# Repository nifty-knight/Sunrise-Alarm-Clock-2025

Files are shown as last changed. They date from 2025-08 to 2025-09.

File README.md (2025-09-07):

# Sunrise-Alarm-Clock-2025

Do you hate the sound of your alarm in the morning? Would you rather wake up peacefully, gently, and - most importantly - <i>quietly</i>?
If so, consider making a Sunrise Alarm Clock! This repo is part of an [instructable tutorial](https://www.instructables.com/DIY-Sunrise-Alarm-Clock-With-Arduino/) on how to do just that.

Note that Full_program_v3.5 is the most updated version; v4 is still in progress.

For those who don't want to click suspicious hyperlinked text: https://www.instructables.com/DIY-Sunrise-Alarm-Clock-With-Arduino/

For a condensed and more technical description of the project, read the Project Description pdf. Note that the corresponding code can be found in the oo-refactoring branch of this repository.

## Clock User Instructions

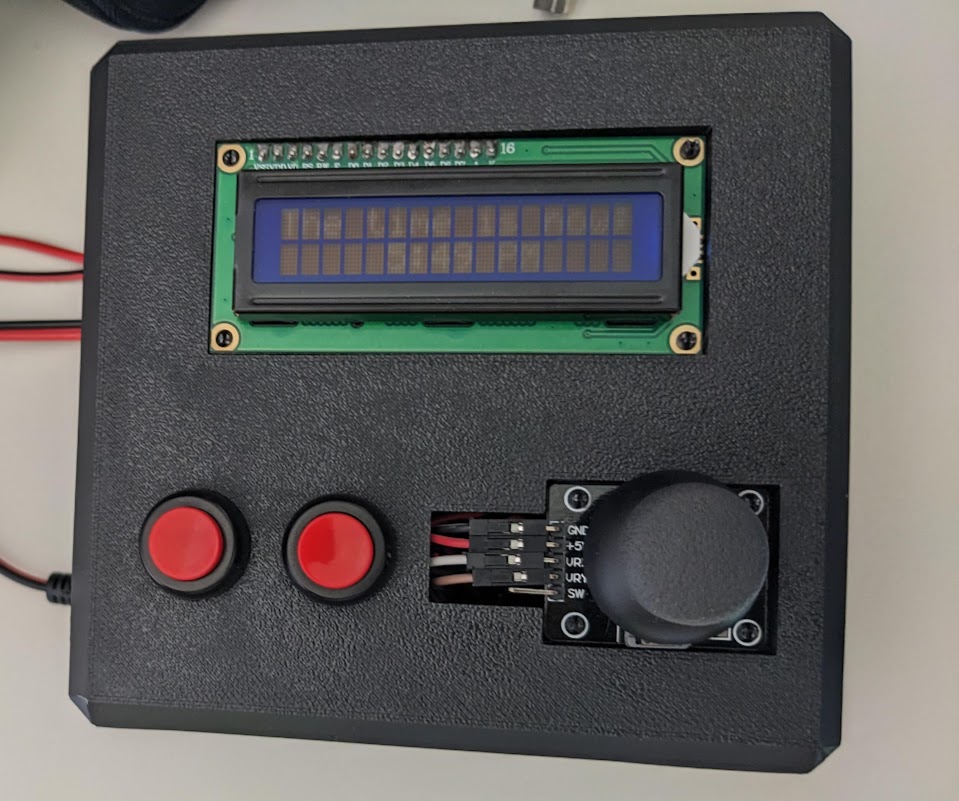
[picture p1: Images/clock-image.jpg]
Clock Image


### Display
Pressing the select button will turn the display on, which shows a user menu. From the menu, you can:

**Set Alarm Time** - 
This will lead to a series of menus where you can select AM/PM, hour, and minute (in 15-minute increments) for the desired
alarm time. Toggle the joystic up and down to change the values, and use the Select button to select desired values. Moving the
joystick to the right will also select the current value, while moving the joystick to the left will go back to the previous menu 
or cancel the set alarm process if there are no more previous menus. Currently, only one alarm can be set at a time.

**Set Current Time** - 
This works similarly to setting the alarm time, but it affects the current time stored by the clock module. Caution! Currently, it 
can only be set in 15-minute increments (0, 15, 30, 45).

**Move Time Forwards 1hr** -
This function is meant for daylight savings time; select this menu to move the current time forwards one hour.

**Move Time Backwards 1 hr** -
This function is meant for daylight savings time; select this menu to move the current time backwards one hour.

**Toggle Alarm** -
Selecting this menu option will not change the time set for the alarm, but will toggle its on/off state (ex. if the alarm was previously ON, 
it will be OFF after toggling, and vice versa). If the alarm is OFF, the light will not turn on even when the current time matches the set alarm time. 
This provides a quick and easy way to turn on/off the alarm for weekdays/weekends.

### Time Button
The leftmost button is the Time button, press it to display the current time. The display will turn off automatically after 5 seconds.

### Select Button
The rightmost button is the Select button, it is used for selecting menu options.

### Joystick
The joystick is used for switching between menus. It can also be used for selection and cancellation (the 'back' function) when setting times.

### Start/Reset
The current time must be set on program start, but afterwards it will retain the time even if the Arduino loses power, as long as there is a battery powering the RTC. 
However, currently any set alarm will have to be reset if the Arduino loses power or if the program is reset.

## Notes
- Note that v3.5 is the most updated version; v4 is still in progress.
- This code is still being updated and improved, check back for better and more robust versions of the program!

## Features to add
- Add unit testing framework
- Add interruptibility to all reads/displays, right now only some of them are interruptible
- Include a function to prevent the user from setting an alarm less than fadetime mins from now
- Edit program to use getFadeStartTime() instead of setFadeStartTime() - all tests for program first - this is refactoring
- Check that all functions to do with milliseconds and longs are subtraction - no addition to prevent rollover errors
- Add function so that looking at menus doesn't affect the light turning on or not
- Modify setHour() and setMin() functions to reduce coupling of cursor variable with magic number
- Add fun messages to print to lcd using displayTime
    - "The time is now..." 
    - LUNCHTIME
    - Why are you awake? You have 1 hrs, 39 mins, and 56 secs of sleep time left
    - 11AM!!! YOU'RE LATE FOR WORK/SCHOOL haha just kidding it's actually ___ (real time)
    - Do you really need to pee again? I need to sleep too...
    - ... it's the witching hour~~ ...
- Allow current time and/or alarm time to be set at any minute (not just 15-minute increments) - might use sliders for two unit places (eg. _ _ )
- Potentially add support for multiple alarms

## Changelog/Completed Features

v3.5 - Added functionality to prevent the time from resetting if the Arduino loses power (requires cell battery for the RTC module)

v3 - Added interruptibility for reading current time & displaying current alarm state - pressing the Select button returns to the mains menu

v3 - Added 'back' functions and cancellation for setting alarm/current time

v3 - Added menu options for daylight savings to move the current time ahead/behind 1 hr

v2 - More custom arrow icons, changed menu switch directions (up/down instead of left/right)

v1 - Added custom icons for arrows

v1 - Added a timer to automatically switch off the LCD after 25 secs of inactivity, which resets on button click/joystick movement

v1 - Created menus for setting alarm time & current time

v1 - Added LCD menu switching with the joystick

v1 - Added functionality to display the current time for 5 seconds on Time button press

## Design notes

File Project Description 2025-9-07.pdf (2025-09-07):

Breanne Chan

Project Description: Sunrise Alarm Clock

The Sunrise Alarm Clock was a personal project that I designed and built from scratch, involving designing and soldering an electronic circuit and components, developing C++ code for an Arduino Uno, and designing a 3D-printed case using a CAD program.

Electronics
Circuit Diagram

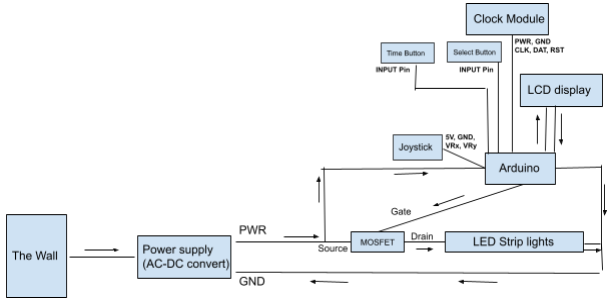
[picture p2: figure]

There were several technical challenges involved in the design of this circuit. First, I had to create a system where a light source would gradually increase in brightness. Although I initially tried to use an array of small LED lights, lighting up one row at a time, I found that they were not bright enough to serve as a wakeup system. Ultimately, I realized that I needed brighter lights, which required more power than the Arduino could output. Changing the light source meant I needed to carefully consider the appropriate power source for my project, and also find a separate device to modulate the brightness of the light source. Eventually, I settled on using 12V LED strip lights, since the Arduino Uno could also be powered with 12 volts, wired the Uno’s lower-voltage digital PWM pins to an external MOSFET module serving as the brightness controller, and used a wall outlet for consistent, reliable power.

In the final circuit, an Arduino Uno serves as the “brain” for the project, controlling the light and user input/output system. The circuit makes use of a DS1302 Real-Time Clock module to keep accurate track of time, and an N-channel MOSFET to control the brightness of the LED strip light. Two momentary push buttons and a joystick are used to set or modify the alarm or current time, while a 16x2 liquid crystal display shows information to the user. A 12V DC power supply converts the power provided from a wall outlet into the appropriate voltage and current levels for the Arduino and LED strip lights.

Code

In my first iteration of the code, my primary aim was simply to build a full, working system. To do so, I broke down the large goal - creating a sunrise alarm clock - into several smaller chunks, such as getting the light system working, creating a user input/output system, implementing functionality to modify and track time accurately, etc. and wrote programs to solve each of those smaller problems independently. While making these programs, I was constantly researching and reading documentation to understand the capabilities of external software libraries that I used as well as the inputs/outputs of my hardware. Finally, I used what I’d learnt in the process of creating each small program to recombine them and create the complete system.

However, the original program I created was not without flaws. For instance, it was written in a messy procedural pattern and was neither easy to read nor simple to extend. Furthermore, the logic I used sometimes induced unwanted blocking, where the microprocessor was waiting for user input and could not check whether it was time for the light system to start. Currently, I am developing a refactored version of my original code to address all these problems, where I am applying object-oriented design concepts to create a class hierarchy which increases cohesiveness, creates modularity, and decouples separate functionality from each other. Additionally, I plan to use finite-state machine models with a set number of states to represent a tick-based update loop, preventing unwanted blocking.

UML Class Diagram V1

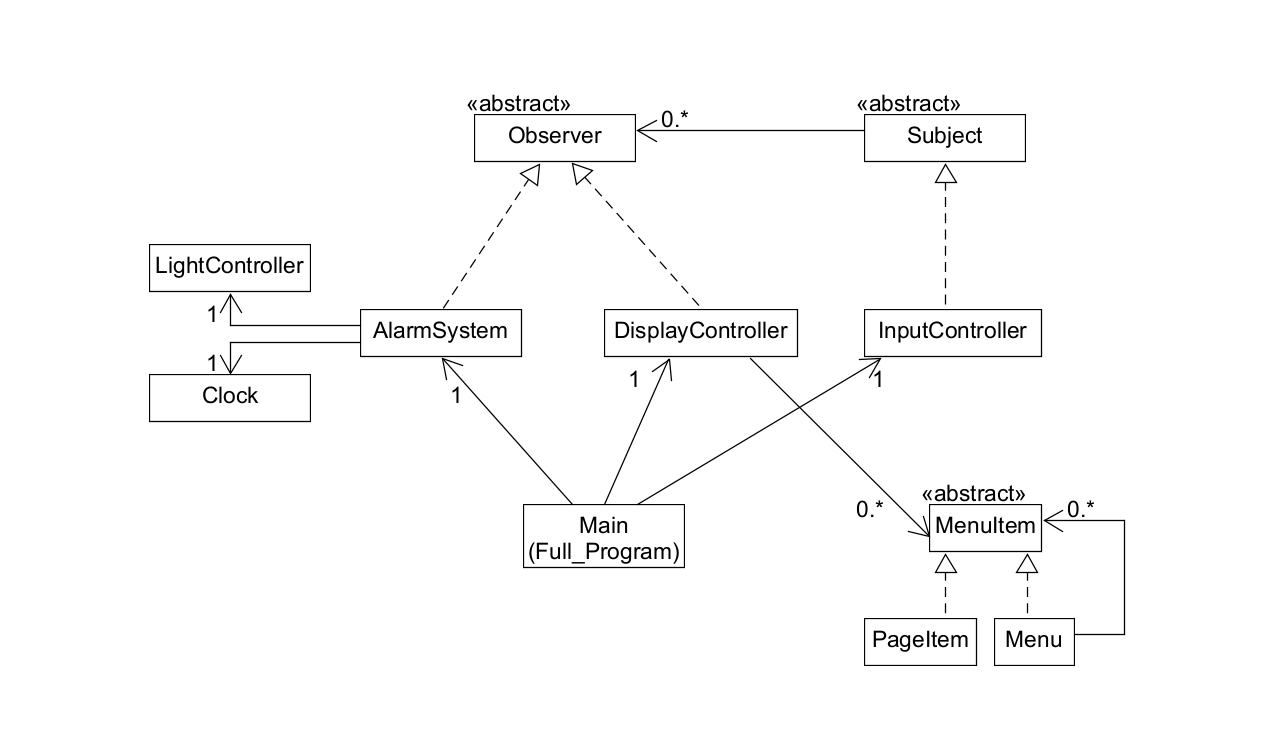
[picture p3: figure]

- Initial ideas for class hierarchy
- Main is the .ino file from which the program starts
- InputController listens for input from the user, notifies AlarmSystem and DisplayController to act
- Pages/Menus in the user display are represented by the composite MenuItem pattern

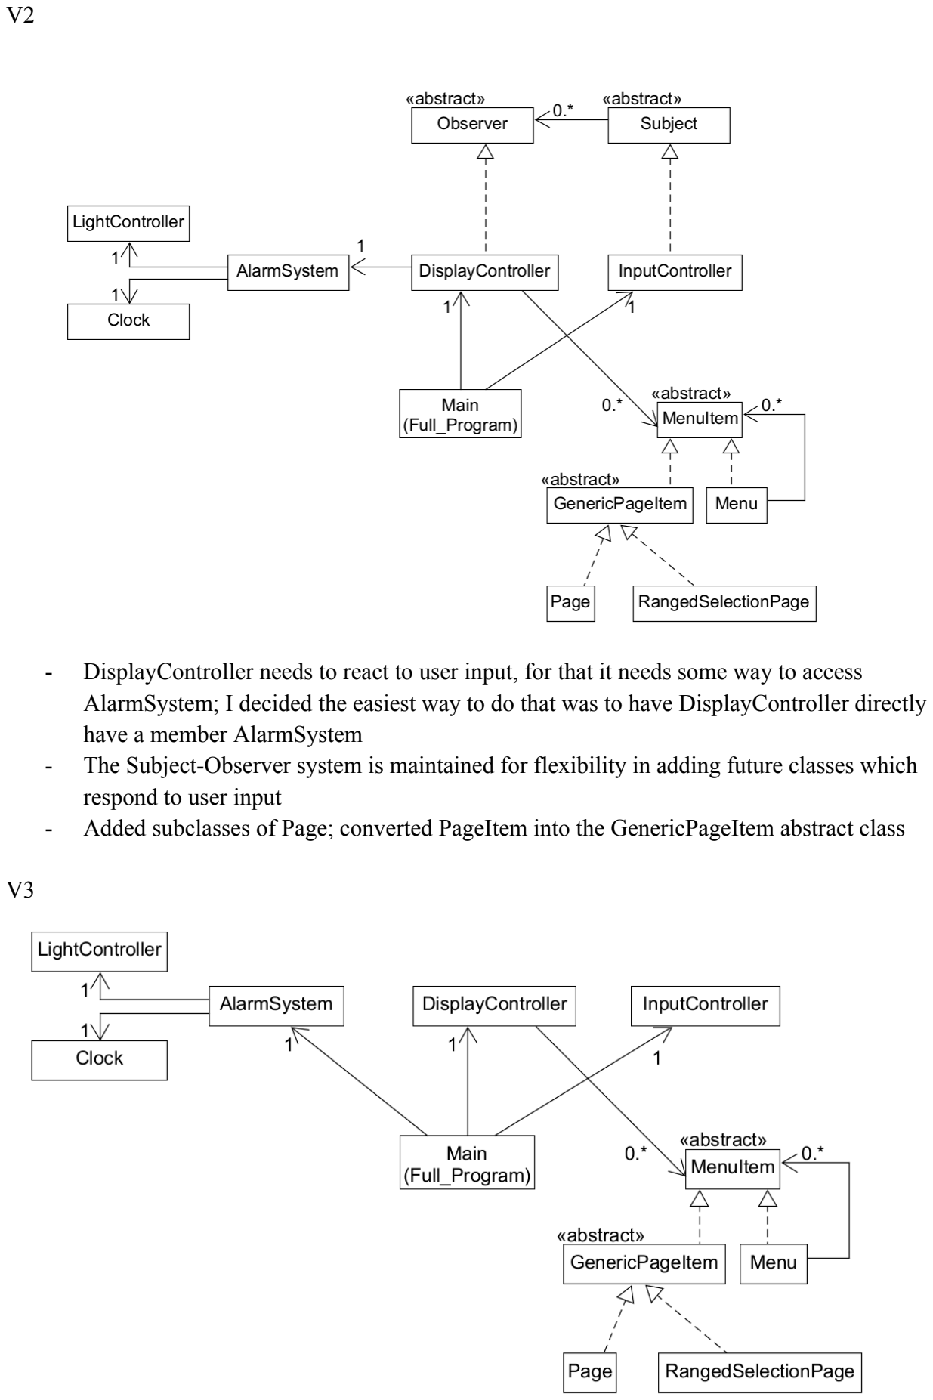
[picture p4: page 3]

V2

- DisplayController needs to react to user input, for that it needs some way to access AlarmSystem; I decided the easiest way to do that was to have DisplayController directly have a member AlarmSystem
- The Subject-Observer system is maintained for flexibility in adding future classes which respond to user input
- Added subclasses of Page; converted PageItem into the GenericPageItem abstract class

V3

- Realized that since Main instantiates and can access a member DisplayController and InputController, the Subject-Observer pattern only increases coupling of the program
- Removed the Subject-Observer system entirely, DisplayController will be the class whose responsibility is to process all user input

V4

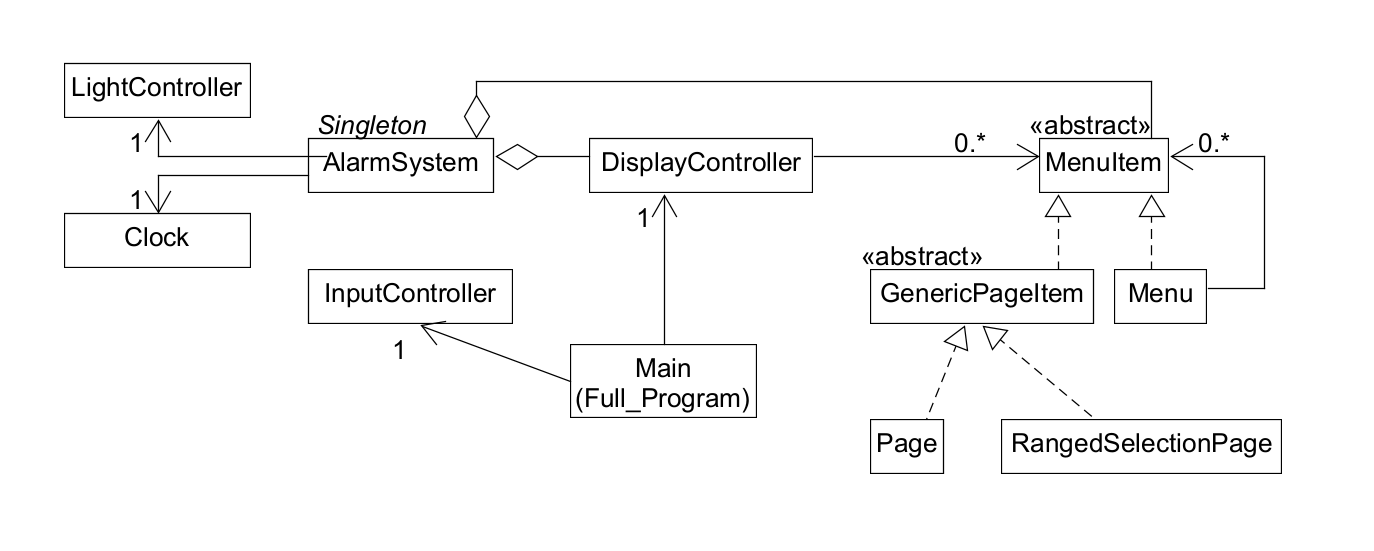
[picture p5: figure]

- Refactored AlarmSystem into a singleton class - since there really only should be one AlarmSystem
- Note that the notation for singleton is not typical; I just wanted to explicitly write it since I have not included fields and methods in the diagrams
- Note that I also have not included the association for AlarmSystem to itself (where it contains a field for an instance of itself)

Potential Future Improvements
- Refactor DisplayController, InputController, potentially also LightController and Clock to be singleton classes
- They each correspond to particular hardware modules
- However, doing this may increase complexity of code without much benefit
- May add a RangedSelectionMenu as a child of Menu
- Alternatively, may add RangedSelectionBehaviour class and implement a composition structure with both Page and Menu
- Both DisplayController and MenuItem contain associations with AlarmSystem; however, DisplayController also contains a collection of MenuItem. Can I remove the extra reference from DisplayController to reduce coupling?

Computer-Aided Design

The CAD design for this project included a base with snap-fit plug mounts to hold the PCB modules and a lid with similar mounts for a 16x2 LCD, joystick, and two panel mount buttons.

I started the design by creating mounts for each of the PCB modules (Arduino, RTC, MOSFET, etc). I initially started with a design that partially covered each side of the module. However, while researching alternative solutions, I came across a Medium article (https://medium.com/@williamtech/3d-printing-snap-fit-mounting-plugs-for-pcbs-a2668a159a8c) experimenting with snap-fit plugs, and consequently decided to try and create my own in Onshape, based off of William Andrews' design. I tested several different sizes and tolerances before settling on a final size and creating prototype mounts for each module.

After that, I started experimenting with lid design. I tried a few versions of a spring-loaded lid, but ultimately pivoted to a much simpler brim design which was simple and clean-looking. However, the new lid design was causing a problem; because the lid was hollow on the inside, but the snap-fit plugs stuck out of the top, each print required a lot of support, no matter how I oriented the design. I wasn't sure how to resolve this problem until a family member suggested that I recess the plugs into the lid, so that the top of each sat flush with the surface of the lid. After some trial and error, I was able to create a final lid design that reduced my material use by 15% and decreased print time by 40 minutes!

Note: I also wrote an in-depth Instructables tutorial (https://www.instructables.com/DIY-Sunrise-Alarm-Clock-With-Arduino/) for this project, which was featured by the editors of the site and garnered over 100 views in its first two weeks after publishing.

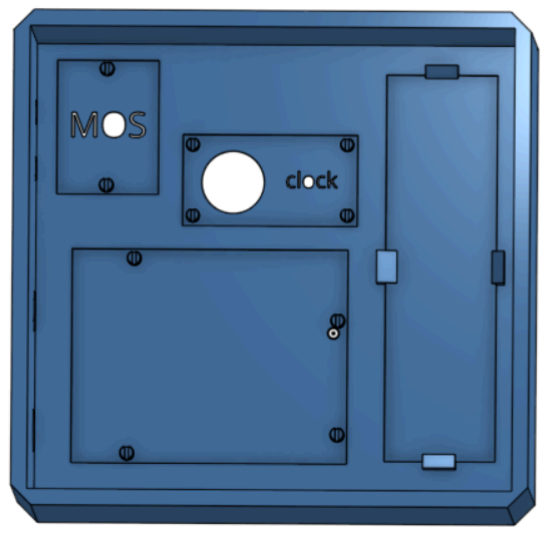
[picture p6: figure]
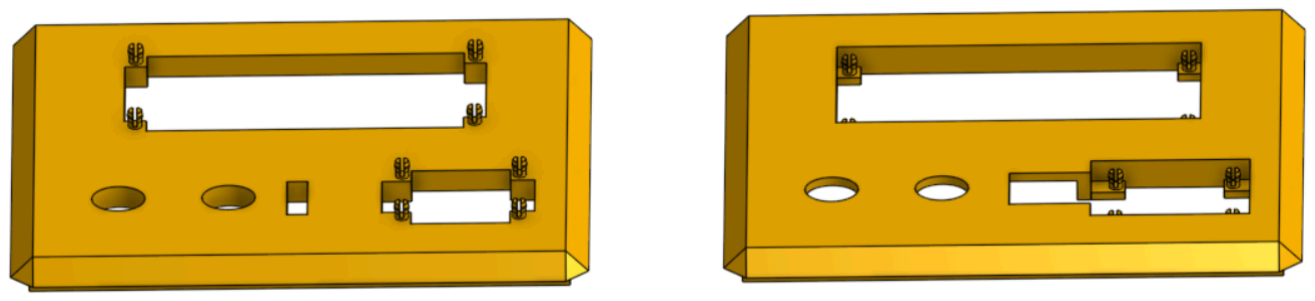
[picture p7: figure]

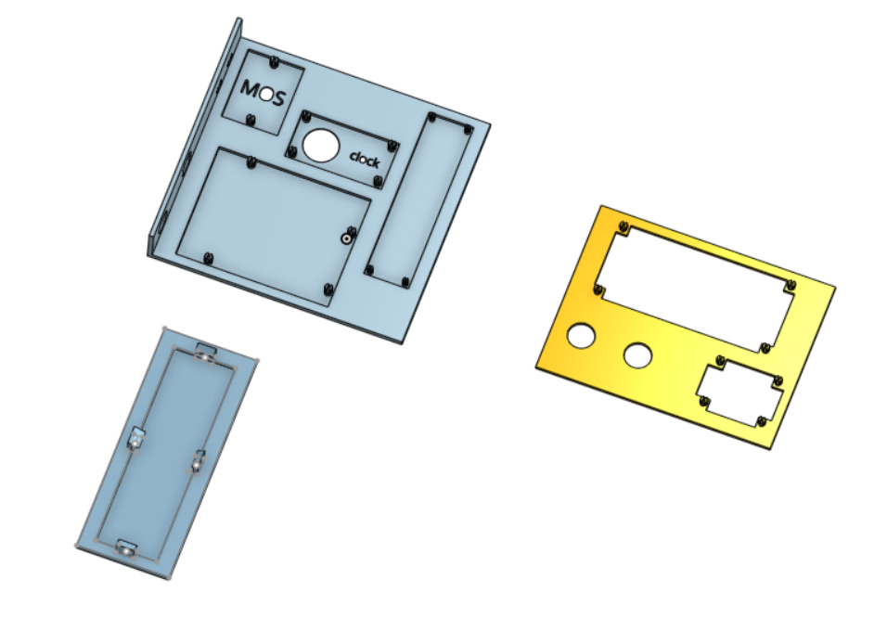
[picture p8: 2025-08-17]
Images/Onshape Pictures/Screenshot 2025-08-16 085841.png

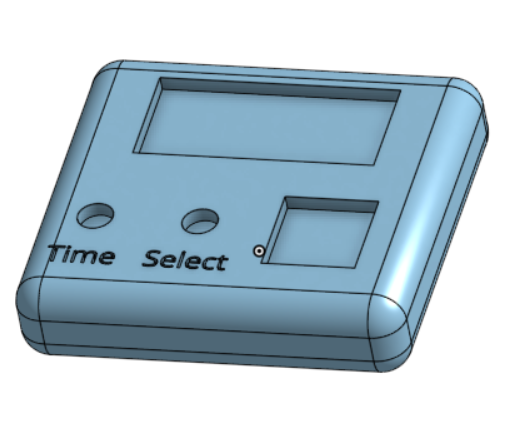
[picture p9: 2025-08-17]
Images/Onshape Pictures/Screenshot 2025-08-16 090458.png

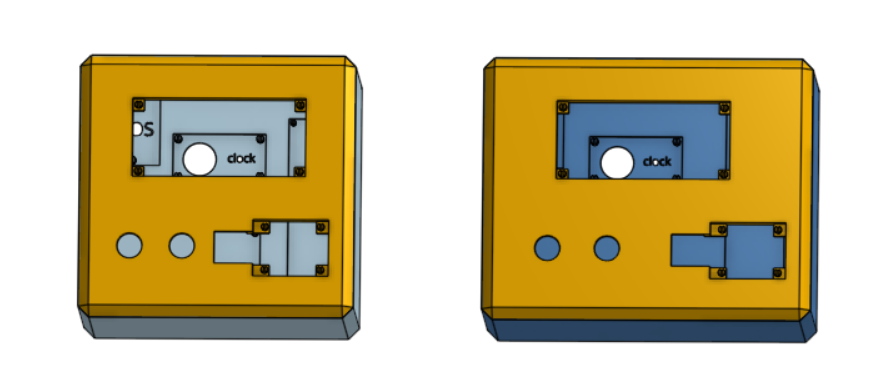
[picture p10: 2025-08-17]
Images/Onshape Pictures/Screenshot 2025-08-16 092152.png

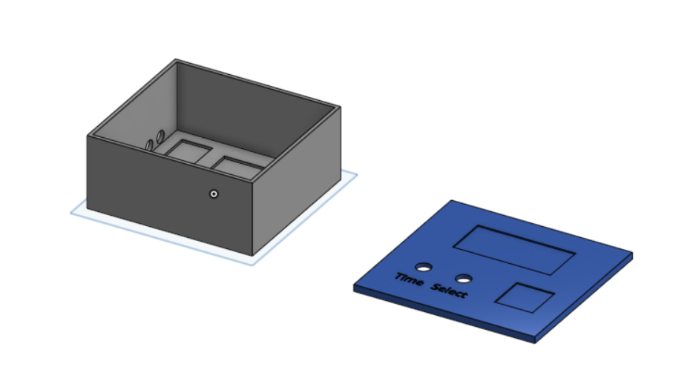
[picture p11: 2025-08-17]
Images/Onshape Pictures/Screenshot 2025-08-16 090216.png

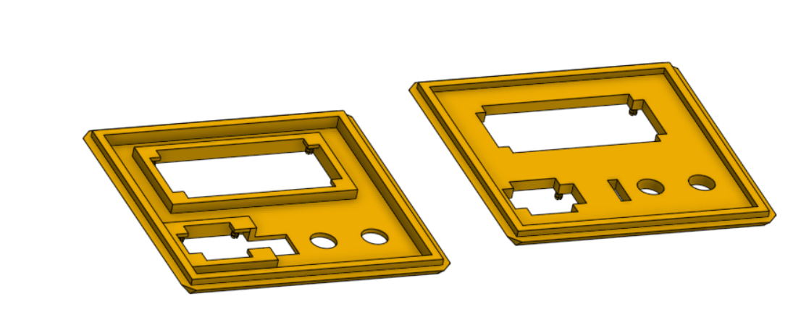
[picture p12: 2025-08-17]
Images/Onshape Pictures/Screenshot 2025-08-16 090546.png

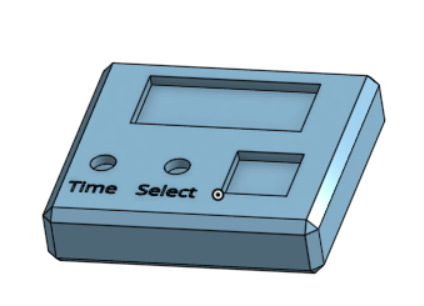
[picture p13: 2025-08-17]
Images/Onshape Pictures/Screenshot 2025-08-16 090327.png

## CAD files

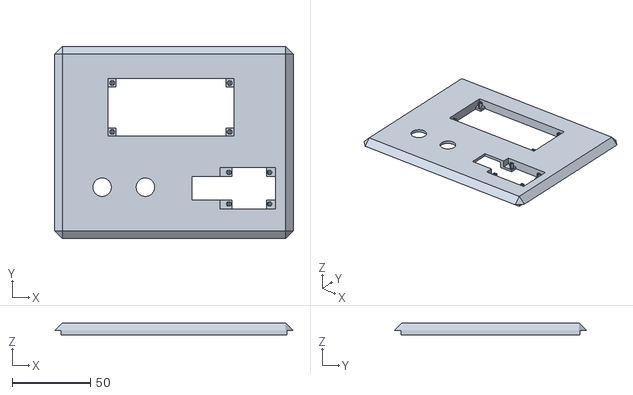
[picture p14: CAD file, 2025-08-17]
STL Files/Lid - Large.stl
153.0 x 123.0 x 8.00

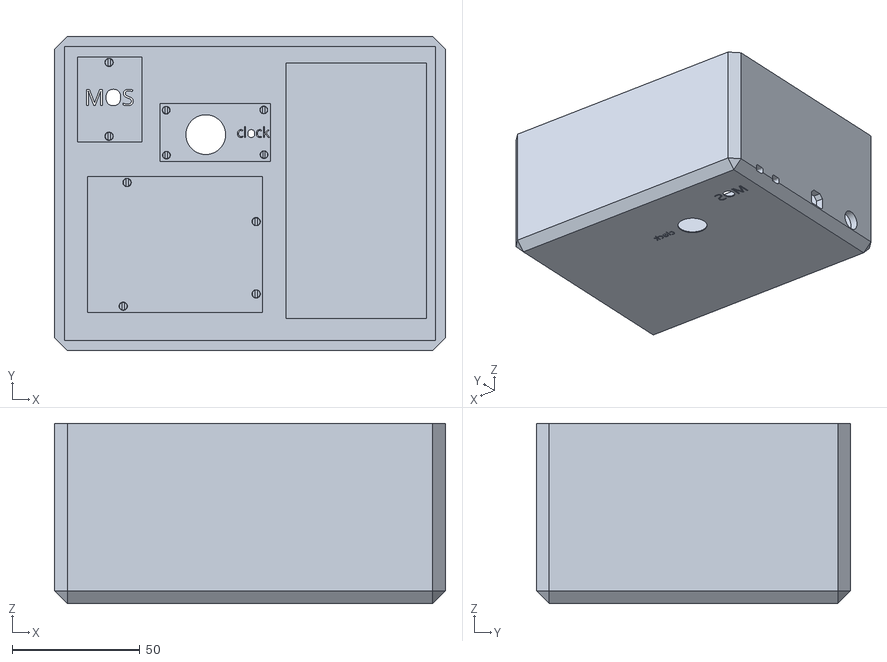
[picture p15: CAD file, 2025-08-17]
STL Files/Box - Large.stl
153.0 x 123.0 x 70.5

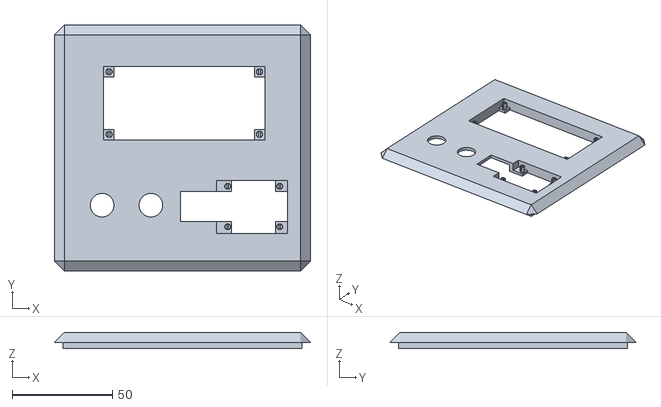
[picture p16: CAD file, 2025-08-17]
STL Files/Lid - Original.stl
128.0 x 123.0 x 8.00

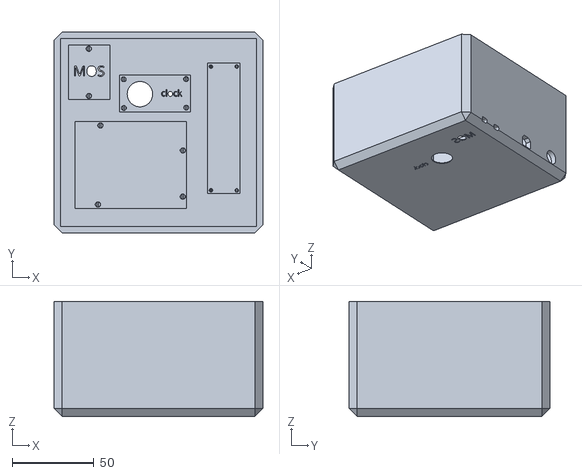
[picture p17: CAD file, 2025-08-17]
STL Files/Box - Original.stl
128.0 x 123.0 x 70.5

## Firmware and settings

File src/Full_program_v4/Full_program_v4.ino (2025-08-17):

#include <LiquidCrystal.h>
#include <Arduino.h>
#include <Ds1302.h>

void on();
void off();
void displayMainMenu();
void selectPage(int index);
bool joystickUp();
bool joystickDown();
bool joystickLeft();
bool joystickRight();
void switchPage(int index);
String setPeriod();
int setHour();
int setMin();
int convertTo24HrTime(int hr, String s);
void daylightSavingChange(int change);
bool pastFadeStartTime(Ds1302::DateTime alarm);
void printUpArrow();
void printDownArrow();
// void printLeftArrow();
// void printRightArrow();
void turnLightOff();
void printCurrentTime();
void printAlarmState();
void resetActivityTimer();

byte UpArrow[8] = {
  0b00000,
  0b00000,
  0b00000,
  0b00100,
  0b01110,
  0b11111,
  0b00000,
  0b00000
};

byte DownArrow[8] = {
  0b00000,
  0b00000,
  0b11111,
  0b01110,
  0b00100,
  0b00000,
  0b00000,
  0b00000
};

byte RightArrow[8] = {
  0b00000,
  0b01000,
  0b01100,
  0b01110,
  0b01110,
  0b01100,
  0b01000,
  0b00000
};

byte LeftArrow[8] = {
  0b00000,
  0b00010,
  0b00110,
  0b01110,
  0b01110,
  0b00110,
  0b00010,
  0b00000
};

const int delayTime = 525;
const int readTime = 3500;
const int noActivityTime = 20000; // 25 secs

const int PIN_CLK = 7;
const int PIN_DAT = 6;
const int PIN_ENA = 5;  // RST on the module

const String PERIOD_ERROR = "ERROR";
const int HOUR_ERROR = -1;
const int MIN_ERROR = -1;
const int YEAR_ERROR = 0;

// DS1302 RTC instance
Ds1302 rtc(PIN_ENA, PIN_CLK, PIN_DAT);
Ds1302::DateTime alarmTime;
Ds1302::DateTime fadeStartTime;
bool alarmIsOn = false;        // initialized as off originally

// Creates an LCD object. Parameters: (rs, enable, d4, d5, d6, d7)
LiquidCrystal lcd(13, 11, 10, 8, 3, 2);
const uint8_t backlightPin = A5; // A on LCD
bool displayOn = true;

const uint8_t displayButtonPin = A3; // displays current time when pressed - previously A0
const uint8_t selectButtonPin = A4; // used to select options for menu and turn the light off
int index;                     // menu index (aka menu "page/tab")
const int MAX_MENU_INDEX = 4;  // represents 5 allowed pages for main menu - set alarm, set current time, current time +1hr, current time -1hr, toggle alarm

const uint8_t X_pin = A1;  // analog pin connected to X output of joystick
const uint8_t Y_pin = A0; // analog pin connected to Y output of joystick
int X_pos;
int Y_pos;

unsigned long startTime; // starting time for activity timer

const int ledPin = 9; // MOSFET control pin (SIG)
bool lightIsOn = false; // keeps track of the state of the LED light; off initially
float fadeLength = 20; // time in minutes for the light to go from 0 to full brightness
int brightness = 0; // 0-255
int brightnessMultiplier = 1; // Range from 1..*, the smaller the number the brighter it gets
unsigned long long ledStartTime; // used for controlling light brightness
unsigned long long waitTime; // the amount of delay before increasing the brightness of the light

void setup() {
  pinMode(X_pin, INPUT);
  pinMode(Y_pin, INPUT);
  pinMode(selectButtonPin, INPUT);
  pinMode(displayButtonPin, INPUT);
  pinMode(ledPin, OUTPUT);
  turnLightOff();
  startTime = millis();
  ledStartTime = millis();

  if (rtc.isHalted()) {
    rtc.init();

    Ds1302::DateTime currentTime = {
      .year = 2025,
      .month = Ds1302::MONTH_AUG,
      .day = 9,
      .hour = 16,
      .minute = 48,
      .second = 0,
      .dow = Ds1302::DOW_SAT
    };

    rtc.setDateTime(&currentTime);
  }

  pinMode(backlightPin, OUTPUT);

  // set up the LCD's number of columns and rows:
  lcd.begin(16, 2);
  // Clears the LCD screen
  lcd.clear();
  lcd.createChar(2, UpArrow);
  lcd.createChar(3, DownArrow);
  off();
}

void loop() {

  if (pressed(displayButtonPin)) {
    on();
    printCurrentTime();
  }

  if (pressed(selectButtonPin)) {

    if (lightIsOn) {
      turnLightOff();
      delay(delayTime);
    } else if (displayOn) {
      resetActivityTimer();
      selectPage(index);
    } else {
      resetActivityTimer();
      displayMainMenu();
    }
  }

  if (displayOn) {
    if (joystickUp()) switchPage(-1);
    else if (joystickDown()) switchPage(1);
  }

  if (displayOn && ((millis() - startTime) > noActivityTime)) {
    off();
  }

  if (alarmIsOn && !lightIsOn && nowIsTime(fadeStartTime)) {
    setupFade();
  } else if (alarmIsOn && lightIsOn && (brightness < 255)) { // light is on, not at full brightness
    if ((millis() - ledStartTime) >= waitTime) {
      brightness++;
      analogWrite(ledPin, brightness);
      ledStartTime = millis();
    }

  }
}

// EFFECTS: Sets up the variable needed to start fading in the light in the while loop
void setupFade() {
  lightIsOn = true;
  waitTime = abs(round(fadeLength * (60L * 1000L) / 255.0)) * brightnessMultiplier; // * multiplier because I find full brightness too much
  brightness = 1;
  analogWrite(ledPin, brightness);
  ledStartTime = millis();
}

// REQUIRES: time is not null
// EFFECTS: Returns true if the current time matches the given time (up to the second)
//          note: returns true if the hour and minute and second all match (when setting alarm time, give user option only for hour and minute, set time to zero)
//               - matches second +- 8 secs
bool nowIsTime(Ds1302::DateTime time) {
  Ds1302::DateTime now;
  rtc.getDateTime(&now);

  if ((now.hour == time.hour) && (now.minute == time.minute) 
      && ((now.second <= time.second + 8) || (now.second >= time.second - 8))) return true;
  else {
    return false;
  }
}

// EFFECTS: Returns true if the button connected to the given pin is being pressed
//          - note that the buttons I am using are backwards - let current flow when not pressed, block current when they are pressed - eg. 0 = pressed, 1 = not pressed
// FOR INVERTED BUTTONS
bool pressed(int pin) {
  if (digitalRead(pin)) {
    return false;
  } else {
    return true;
  }
}

// EFFECTS: Returns true if the button connected to the given pin is being pressed
//          - note that the buttons I am using are backwards - let current flow when not pressed, block current when they are pressed - eg. 0 = pressed, 1 = not pressed
// FOR NON-INVERTED BUTTONS - uncomment the below pressed() function and comment out the above pressed() function
// bool pressed(int pin) {
//   if (digitalRead(pin)) {
//     return true;
//   } else {
//     return false;
//   }
// }

// EFFECTS: Guides user through setting a new time and returns the time
Ds1302::DateTime userSetTime() {

  Ds1302::DateTime currentTime;
  rtc.getDateTime(&currentTime); 

  int hr = 1;
  int min = 0;
  int year = currentTime.year;

  String period = setPeriod();
  if (period.equals(PERIOD_ERROR)) {
    year = YEAR_ERROR;
  } else {
    while (true) {
      hr = setHour();
      if (hr == HOUR_ERROR) {
        period = setPeriod();
        if (period.equals(PERIOD_ERROR)) {
          year = YEAR_ERROR;
          break;
        }
      } else {
        min = setMin();
        if (min == MIN_ERROR) {
          continue;
        } else {
          hr = convertTo24HrTime(hr, period);
          break;
        }
      }
    }
  }

  Ds1302::DateTime time = { // note that day, month, dow are fairly random; only time (and year for the error) matters here
    .year = year,
    .month = currentTime.month,
    .day = currentTime.day,
    // .day = day,--> this should be the final version
    .hour = hr,
    .minute = min,
    .second = 0,
    .dow = currentTime.dow
  };

  return time;
}

// REQUIRES: LCD display is on
// EFFECTS: does the period selection menu, allows user to select AM or PM, returns user selection
//          note: 0 = AM, 1 = PM
String setPeriod() {
int cursor = 0;
  lcd.clear();
  lcd.setCursor(3, 0);
  lcd.print("Select: AM");
  lcd.setCursor(14, 0);
  printUpArrow();
  lcd.setCursor(14, 1);
  printDownArrow();
  delay(delayTime);

  while (true) {
    if (pressed(selectButtonPin) || joystickRight()) {
      delay(delayTime);
      if (cursor == 0) return "AM";
      else return "PM";
    } else if (joystickUp()) {
      cursor = 0;
      lcd.setCursor(11, 0);
      lcd.print("A");
    } else if (joystickDown()) {
      cursor = 1;
      lcd.setCursor(11, 0);
      lcd.print("P");
    } else if (joystickLeft()) {
      delay(delayTime);
      // Serial.print("To the left\n");
      return PERIOD_ERROR;
    }
  }
}

// EFFECTS: does the minute selection menu, allows user to select an hour between 1-12 inclusive, returns user selection
int setHour() {
  int cursor = 7;
  lcd.clear();
  lcd.setCursor(1, 0);
  lcd.print("Set Hour: 07 "); // NOTE: this has to change along w/ initial cursor number if changed
  printUpArrow();
  lcd.setCursor(14, 1);
  printDownArrow();
  delay(delayTime);

  while (true) {
    if (pressed(selectButtonPin) || joystickRight()) {
      delay(delayTime);
      return cursor;
    } else if (joystickUp()) {
      if (cursor <= 1) cursor = 12;
      else cursor--;
      lcd.setCursor(11, 0);
      if (cursor < 10) lcd.print("0");
      lcd.print(cursor);
      delay(delayTime);
    } else if (joystickDown()) {
      if (cursor >= 12) cursor = 1;
      else cursor++;
      lcd.setCursor(11, 0);
      if (cursor < 10) lcd.print("0");
      lcd.print(cursor);
      delay(delayTime);
    } else if (joystickLeft()) {
      delay(delayTime);
      return HOUR_ERROR;
    }
  }
}

// EFFECTS: does the minute selection menu, allows user to select a minute between 0-59, returns user selection
// for now only supports 15-min increments -> in the future may support 5-min increments
int setMin() {
  int range[] = {0,15,30,45};
  int size = 4; // size of the range[] array

  int cursor = 0;
  lcd.clear();
  lcd.setCursor(2, 0);
  lcd.print("Set Min: 00 "); // NOTE: this has to change along w/ initial cursor number if changed
  lcd.setCursor(14, 0);
  printUpArrow();
  lcd.setCursor(14, 1);
  printDownArrow();
  delay(delayTime);

  while (true) {
    if (pressed(selectButtonPin) || joystickRight()) {
      delay(delayTime);
      return range[cursor];
    } else if (joystickUp()) {
      if (cursor <= 0) cursor = (size - 1);
      else cursor--;
      lcd.setCursor(11, 0);
      if (range[cursor] < 10) lcd.print("0");
      lcd.print(range[cursor]);
      delay(delayTime);
    } else if (joystickDown()) {
      if (cursor >= (size - 1)) cursor = 0;
      else cursor++;
      lcd.setCursor(11, 0);
      if (range[cursor] < 10) lcd.print("0");
      lcd.print(range[cursor]);
      delay(delayTime);
    } else if (joystickLeft()) {
      return MIN_ERROR;
    }
  }
}

// EFFECTS: Takes an hour in 12-hr time and AM or PM, and determines the time in 24-hr time
int convertTo24HrTime(int hour, String period) {
  if (period == "PM") {
    return hour += 11;
  } else return hour - 1;
}

// EFFECTS: calls new routine depending on the current menu and page
void selectPage(int index) {
  delay(delayTime);
  switch (index) {
    case 0: {
      alarmIsOn = true;
      displayMainMenu();
      Ds1302::DateTime temp = userSetTime();
      if (pastFadeStartTime(temp)) { // If it is past the start time, don't let the user set the alarm
        lcd.clear();
        lcd.setCursor(1, 0);
        lcd.print("Alarm not set");
        lcd.setCursor(0, 1);
        lcd.print("Too close to now");
        delay(readTime);
        displayMainMenu();
      } else if (temp.year != YEAR_ERROR) { // If year==YEAR_ERROR, that means user cancelled
        alarmTime = temp;
        setFadeStartTime();
        printAlarmState(); 
      } else {
        lcd.clear();
        lcd.setCursor(3, 0);
        lcd.print("Set alarm");
        lcd.setCursor(3, 1);
        lcd.print("cancelled");
        delay(readTime);
        displayMainMenu();
      }
      break;
    }
    case 1: {
      Ds1302::DateTime temp = userSetTime();
      if (temp.year != YEAR_ERROR) { // If year==YEAR_ERROR, that means user cancelled
        rtc.setDateTime(&temp);
        printCurrentTime();
      } else {
        lcd.clear();
        lcd.setCursor(3, 0);
        lcd.print("Set time");
        lcd.setCursor(3, 1);
        lcd.print("cancelled");
        delay(readTime);
        displayMainMenu();
      }
      break;
    }
    case 2: { // Change time for daylight savings forward 1hr
      daylightSavingChange(1);
      printCurrentTime();
      break;
    }
    case 3: {
      daylightSavingChange(-1);
      printCurrentTime();
      break;
    }
    case 4: {
      alarmIsOn = !alarmIsOn;
      printAlarmState();
      break;
    }
  }
}

// EFFECTS: switch the index and display the next page; 1 = to the right, -1 = to the left, other displays error on LCD
void switchPage(int next) {
  resetActivityTimer();
  if (next == 1) {
    if (index >= MAX_MENU_INDEX) {
      index = 0;
    } else index++;

  } else if (next == -1) {
    if (index <= 0) {
      index = MAX_MENU_INDEX;
    } else index--;

  } else {
    lcd.clear();
    lcd.print("ERROR next,switchPage");
  }

  setPage(index);

  delay(delayTime);
}

// EFFECTS: Turns on the lcd display and backlight and shows the main menu
void displayMainMenu() {
  index = 0;
  on();
  setPage(index);
  delay(delayTime);
}

// EFFECTS: Writes into the LCD display depending on the current menu and the given index
void setPage(int index) {
  lcd.clear();
  lcd.setCursor(0, 0);
  if (index == 0) {
    lcd.print("   Set alarm");
    lcd.setCursor(14, 0);
    printUpArrow();
    lcd.setCursor(14, 1);
    printDownArrow();
    //
  } else if (index == 1) {
    lcd.print("    Set time");  // Set time
    lcd.setCursor(14, 0);
    printUpArrow();
    lcd.setCursor(14, 1);
    printDownArrow();
  } else if (index == 2) {
    lcd.print("   Move time");
    lcd.setCursor(14, 0);
    printUpArrow();
    lcd.setCursor(0, 1);
    lcd.print(" forward 1hr");
    lcd.setCursor(14, 1);
    printDownArrow();
  } else if (index == 3) {
    lcd.print("   Move time");
    lcd.setCursor(14, 0);
    printUpArrow();
    lcd.setCursor(0, 1);
    lcd.print(" backward 1hr");
    lcd.setCursor(14, 1);
    printDownArrow();
  } else if (index == 4) {
    lcd.print(" Toggle alarm ");  // Alarm toggle
    printUpArrow();
    lcd.setCursor(14, 1);
    printDownArrow();
  } else {
    lcd.print("ERROR index out of bounds");
  }
}

// EFFECTS: Prints current time to the LCD, then turns off the display after readDelay sec
void printCurrentTime() {
  lcd.clear();
  lcd.setCursor(0, 0);
  lcd.print("The time is now:");
  lcd.setCursor(5, 1);
  Ds1302::DateTime currentTime;
  rtc.getDateTime(&currentTime);
  lcd.print(getTime(currentTime));

  long now = millis();
  long end = millis() + long(readTime);

  while (now < end) {
    if (pressed(selectButtonPin)) {
      displayMainMenu();
      return;
    }

    now = millis();
  }

  off();
}

// EFFECTS: Prints alarm state (on/off) and time to the LCD, then turns off the display after readDelay sec
// TODO: printCurrentTime & printAlarmState are very similar - combine into one function?
void printAlarmState() {
  lcd.clear();
  lcd.setCursor(0, 0);
  lcd.print(" Alarm is: ");
  if (alarmIsOn) {
    lcd.print("ON");
  } else lcd.print("OFF");
  lcd.setCursor(0, 1);
  lcd.print("Set to: ");
  lcd.print(getTime(alarmTime));
  
  long now = millis();
  long end = millis() + long(readTime);

  while (now < end) {
    if (pressed(selectButtonPin)) {
      displayMainMenu();
      return;
    }

    now = millis();
  }

  off();
}

// EFFECTS: Turns on the lcd display and backlight and shows the current time
void displayTime() {
  on();
  lcd.clear();
  lcd.setCursor(0, 0);
  lcd.print(F("The time is now: "));  // note: could do some funny things depending on the time
  lcd.setCursor(0, 1);
  Ds1302::DateTime now;
  rtc.getDateTime(&now);
  lcd.print(getTime(now));
  delay(4000);
  off();
}

// EFFECTS: Returns true if joystick has been moved upwards
bool joystickUp() {
  if (analogRead(Y_pin) <= 25) {
    return true;
  }
  return false;
}

// EFFECTS: Returns true if joystick has been moved downwards
bool joystickDown() {
  if (analogRead(Y_pin) >= 1000) {
      return true;
    }
    return false;
}

// EFFECTS: Returns true if joystick has been moved to the left
bool joystickLeft() {
  if (analogRead(X_pin) <= 15) {
    return true;
  }
  return false;
}

// EFFECTS: Returns true if joystick has been moved to the right
bool joystickRight() {
  if (analogRead(X_pin) >= 1000) {
    return true;
  }
  return false;
}

// MODIFIES: this - fadeStartTime
// EFFECTS: sets fadeStartTime to be 20 minutes before the given alarmTime - depends on how long I want the fade in to be
void setFadeStartTime() {

  fadeStartTime = alarmTime;

  if (alarmTime.minute >= fadeLength) {
    fadeStartTime.minute = alarmTime.minute - fadeLength;
  } else {
    int minLeft = fadeLength - alarmTime.minute;
    fadeStartTime.minute = 60 - minLeft;
    if (alarmTime.hour > 0) fadeStartTime.hour = alarmTime.hour - 1; 
    else fadeStartTime.hour = 23;
  }
}

// EFFECTS: Returns the time fadeLength minutes before the given alarmTime
Ds1302::DateTime getFadeStartTime(Ds1302::DateTime alarm) {

  int fadeLength = 20; // mins

  Ds1302::DateTime fadeStart = alarm;

  if (alarm.minute >= fadeLength) {
    fadeStart.minute = alarm.minute - fadeLength;
  } else {
    int minLeft = fadeLength - alarm.minute;
    fadeStart.minute = 60 - minLeft;
    if (alarm.hour > 0) fadeStart.hour = alarm.hour - 1; 
    else fadeStart.hour = 23;
  }

  return fadeStart;
}

void daylightSavingChange(int change) {
  Ds1302::DateTime old;
  rtc.getDateTime(&old);
  int newHour = old.hour + change;

  if (newHour < 0) newHour = 23;
  else if (newHour > 23) newHour = 0;

  Ds1302::DateTime newTime = { // note that day, month, year, dow are fairly random; only time matters here
    .year = old.year,
    .month = old.month,
    .day = old.day,
    .hour = newHour,
    .minute = old.minute,
    .second = old.second,
    .dow = old.dow
  };

  rtc.setDateTime(&newTime);
}

// EFFECTS: Returns true if the current time is past the fadeStartTime of the given alarm time (less than fadeLength minutes before alarm should be going off)
// - Makes no assumptions about the exact minute and hour of alarm and current times, even though currently both can only be set in increments of 15 minutes
// Possible solutions
// - calculate the number of minutes based on current time & fadeLength and compare to alarm time
// - Directly compare current time and fadeLength and see which is ahead - not taking into account day, month, year
// - create a list of all not-allowed times using fadeLength, compare each to current time
bool pastFadeStartTime(Ds1302::DateTime alarm) {
  // get fadeStartTime for the given alarm time
  Ds1302::DateTime fadeStart = getFadeStartTime(alarm);

  // TODO: complete this function
  if (true) {

  }

  return true;
}

// EFFECTS: Turns of the LED light
void turnLightOff() {
  lightIsOn = false;
  analogWrite(ledPin, 0);
}

// EFFECTS: Reset activity timer so that screen won't turn off for another 25 secs or so
void resetActivityTimer() {
  startTime = millis();
}

// EFFECTS: Turns on the lcd light and display
void on() {
  lcd.display();
  backlight();
  displayOn = true;
  resetActivityTimer();
}

// EFFECTS: Turns off the lcd light and display
void off() {
  lcd.noDisplay();
  noBacklight();
  displayOn = false;
}

// EFFECTS: Displays up arrow on the lcd display at current cursor position
void printUpArrow() {
  lcd.write(byte(2));
}

// EFFECTS: Displays down arrow on the lcd display at current cursor position
void printDownArrow() {
  lcd.write(byte(3));
}

// EFFECTS: Displays right arrow on the lcd display at current cursor position
void printRightArrow() {
  lcd.write(byte(1));
}

// EFFECTS: Displays left arrow on the lcd display at current cursor position
void printLeftArrow() {
  lcd.write(byte(0));
}

// EFFECTS: Turns backlight on
void backlight() {
  digitalWrite(backlightPin, 1);
}

// EFFECTS: Turns backlight off
void noBacklight() {
  digitalWrite(backlightPin, 0);
}

// EFFECTS: Returns the given time (12-hr) as a string
String getTime(Ds1302::DateTime time) {

  String message = String("");

  if (time.hour < 10) message.concat(' ');
  if (time.hour < 12) message.concat(time.hour + 1);
  else message.concat(time.hour - 11);
  message.concat(':');
  if (time.minute < 10) message.concat('0');
  message.concat(time.minute);  // 00-59
  if (time.hour < 11) message.concat(" AM");
  else message.concat(" PM");

  return message;
}

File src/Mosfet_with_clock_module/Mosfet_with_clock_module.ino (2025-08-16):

#include <Arduino.h>
#include <math.h>
#include <Ds1302.h>

/* MOSFET Testing
- This sketch is for figuring out how to dim/brighten the LEDs using the mosfet

TODO
- Play around with how long it takes to fade in (real life fade will probably be about 10-30 min)
  - Note: Try to customize the brightness a bit so that it initially brightens up very slowly/dimly
    - What's the brightness like at level 1/255? Still seems very bright
DONE
- Fade in the brightness of a single LED with arduino alone
- Fade in brightness of a single LED with mosfet
- Fade in at a certain time - preset on the sketch
- Turn off on the press of a button
- Test the whole thing with the LED strip lights
*/

const int PIN_CLK = 7;
const int PIN_DAT = 6;
const int PIN_ENA = 5; // RST on the module

// DS1302 RTC instance
Ds1302 rtc(PIN_ENA, PIN_CLK, PIN_DAT);

Ds1302::DateTime fadeStartTime;
Ds1302::DateTime currentTime;

const int ledPin = 9;
const int buttonPin = 12;
int brightness = 0; // 0-255
float fadeTime = 20; // time in minutes for the light to go from 0 to full brightness
bool lightIsOn;
int delta = 1; 


void setup() {
  // put your setup code here, to run once:
  rtc.init();
  Serial.begin(9600);
  pinMode(ledPin, OUTPUT);
  pinMode(buttonPin, INPUT);
  lightIsOn = false;
  analogWrite(ledPin, 0);

  fadeStartTime = {
    .year = 24,
    .month = Ds1302::MONTH_APR,
    .day = 26,
    .hour = 17,
    .minute = 19,
    .second = 0,
    .dow = Ds1302::DOW_SAT
  };

  currentTime = {
    .year = 0,
    .month = Ds1302::MONTH_DEC,
    .day = 31,
    .hour = 17,
    .minute = 18,
    .second = 0,
    .dow = Ds1302::DOW_WED
  };

  // just so I know I set the time right
  rtc.setDateTime(&currentTime);
  printTime(currentTime);
  printTime(fadeStartTime);
}

void loop() {
  // put your main code here, to run repeatedly:
  
  Ds1302::DateTime now;
  rtc.getDateTime(&now);

  static uint8_t last_second = 0;
  if (last_second != now.second)
  {
      last_second = now.second;
      if (now.hour < 10) Serial.print('0');
      Serial.print(now.hour);    // 00-23
      Serial.print(':');
      if (now.minute < 10) Serial.print('0');
      Serial.print(now.minute);  // 00-59
      Serial.print(':');
      if (now.second < 10) Serial.print('0');
      Serial.print(now.second);  // 00-59
      Serial.println();
  }

  if (!lightIsOn && nowIsTime(fadeStartTime)) {
    Serial.println("ALARM ALARM ALARM");
    fadeInLight(fadeTime); // should I put fadeInLight to return true?
    lightIsOn = true;
  }

  if (lightIsOn && offButtonPressed()) {
    analogWrite(ledPin, 0);
    lightIsOn = false;
  }
  
}

// REQUIRES: fadeTime > 0
// MODIFIES: this: brightness
// EFFECTS: Calculates the speed at which the bulb should go from 0 to full brightness
//          based on the given fadeTime and changes the brightness of the bulb accordingly
//          note: fadeTime is in minutes, and brightness increase is linear (could change in the future)
void fadeInLight(float fadeTime) {

  long fadeTimeMilliSecs = abs(round(fadeTime * (60L * 1000L)));
  float test = fadeTimeMilliSecs / 255.0;
  long waitTime = round(fadeTimeMilliSecs / 255.0);
  int delta = 1;
  brightness = 0;
  // Serial.println(fadeTime);
  // Serial.println(fadeTimeMilliSecs);
  // Serial.println(test);
  // Serial.println(waitTime);

  while (brightness < 255) {
    analogWrite(ledPin, brightness);
    if ((brightness + delta) <= 255) brightness += delta;
    else brightness = 255;
    delay(waitTime);
  }

  lightIsOn = true;
  return;
}

// EFFECTS: Returns true if the off button is currently being pressed (1), false otherwise
bool offButtonPressed() {
  return digitalRead(buttonPin);
}

// REQUIRES: time is not null
// EFFECTS: Returns true if the current time matches the given time (up to the second)
//          note: returns true if the hour and minute and second all match (when setting alarm time, give user option only for hour and minute, set time to zero)
//               - matches second +- 4 secs
bool nowIsTime(Ds1302::DateTime time) {
  Ds1302::DateTime now;
  rtc.getDateTime(&now);

  if ((now.hour == time.hour) && (now.minute == time.minute) 
      && ((now.second <= time.second + 4) || (now.second >= time.second - 4))) return true;
  else {
    return false;
  }
}

// EFFECTS: Prints the given time (12-hr) to the serial monitor
void printTime(Ds1302::DateTime time) {

  if (time.hour < 10) Serial.print(' ');
  if (time.hour < 12) Serial.print(time.hour + 1);
  else Serial.print(time.hour - 11);
  Serial.print(':');
  if (time.minute < 10) Serial.print('0');
  Serial.print(time.minute);  // 00-59
  Serial.print(':');
  if (time.second < 10) Serial.print('0');
  Serial.print(time.second);  // 00-59
  if (time.hour < 11) Serial.print(" AM");
  else Serial.print(" PM");
  Serial.println();
}

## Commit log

2025-08-16 Fixed variable names in getFadeStartTime()
    [Full_program_v4.ino]
2025-08-17 Added CAD pictures
2025-08-17 Added STL Files
    [Box - Original.stl, Lid - Original.stl]
2025-08-17 Create Full_program_v3.5.ino
    Added feature where current time does not reset even if power to the Arduino is lost (until cell battery runs out of power)
    [Full_program_v3.5.ino]
2025-08-17 Cleaned up notes, added non-inverted pressed() function
    [Full_program_v4.ino]
2025-08-17 Added STL files for large version of clock case and lid
    [Box - Large.stl, Lid - Large.stl]
